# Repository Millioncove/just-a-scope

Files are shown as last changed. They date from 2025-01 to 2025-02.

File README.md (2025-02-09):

<p align="center">
  
</p>

# The simplest oscilloscope imaginable.
just-a-scope is a battery powered, ultra light, and tiny oscilloscope.

Often times when working on embedded projects, once GPIO has just been configured and you take the leap from programming into the real world, you cannot even get a blinky program running. Even if you are lucky enough to succeed in your LED-blinking, whatever you are moving onto next won't work. It is simply way more complicated than a single LED. 

At that point you wish you could "just see the electricity", but you cannot. You wish you had an oscilloscope, but all of the commercially available ones are extremely overkill and way out of budget. This is the problem just-a-scope tries to solve.

just-a-scope is really just an esp32 with some protection, scaling electronics and probes connected to the Analog-to-Digital converter. 9 times out of 10, that's all we'll ever need.

The plot is drawn in a web browser on a device connected over WIFI. At that point you already have the entire plot on your computer, and you can download a .csv file with all measurements made.

## Hardware
The microcontroller is an esp32s3, bought already soldered onto a SEEED Studio XIAO. This is a cheap and very small board which includes a USB-C connector as well as charging electronics for a lithium battery.

When buying one of these boards, you are likely to receive an antenna in the same package. This antenna is known to be unusable due to very poor signal, so a third party antenna must be used.

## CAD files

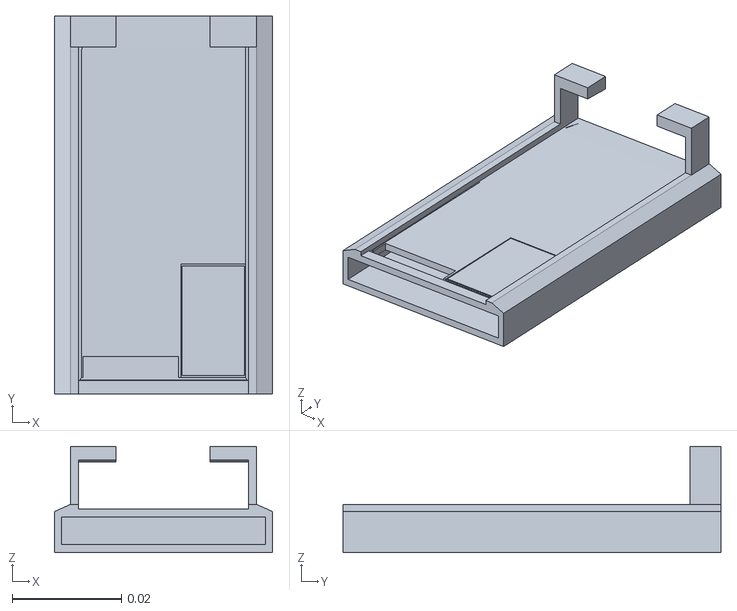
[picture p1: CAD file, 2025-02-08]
CAD/just-a-scope-lid.stl
0.0399 x 0.069 x 0.0194

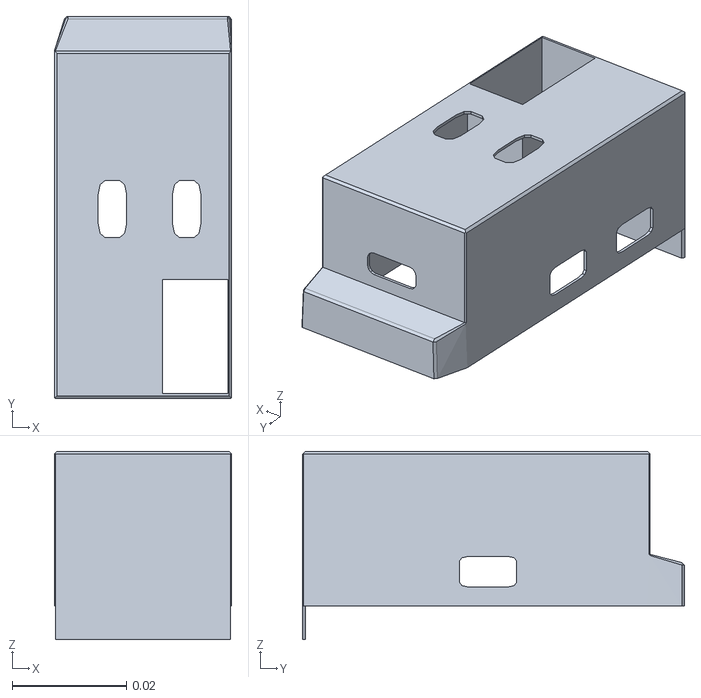
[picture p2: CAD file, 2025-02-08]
CAD/just-a-scope.stl
0.031 x 0.0668 x 0.0329

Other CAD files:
CAD/just-a-scope.blend

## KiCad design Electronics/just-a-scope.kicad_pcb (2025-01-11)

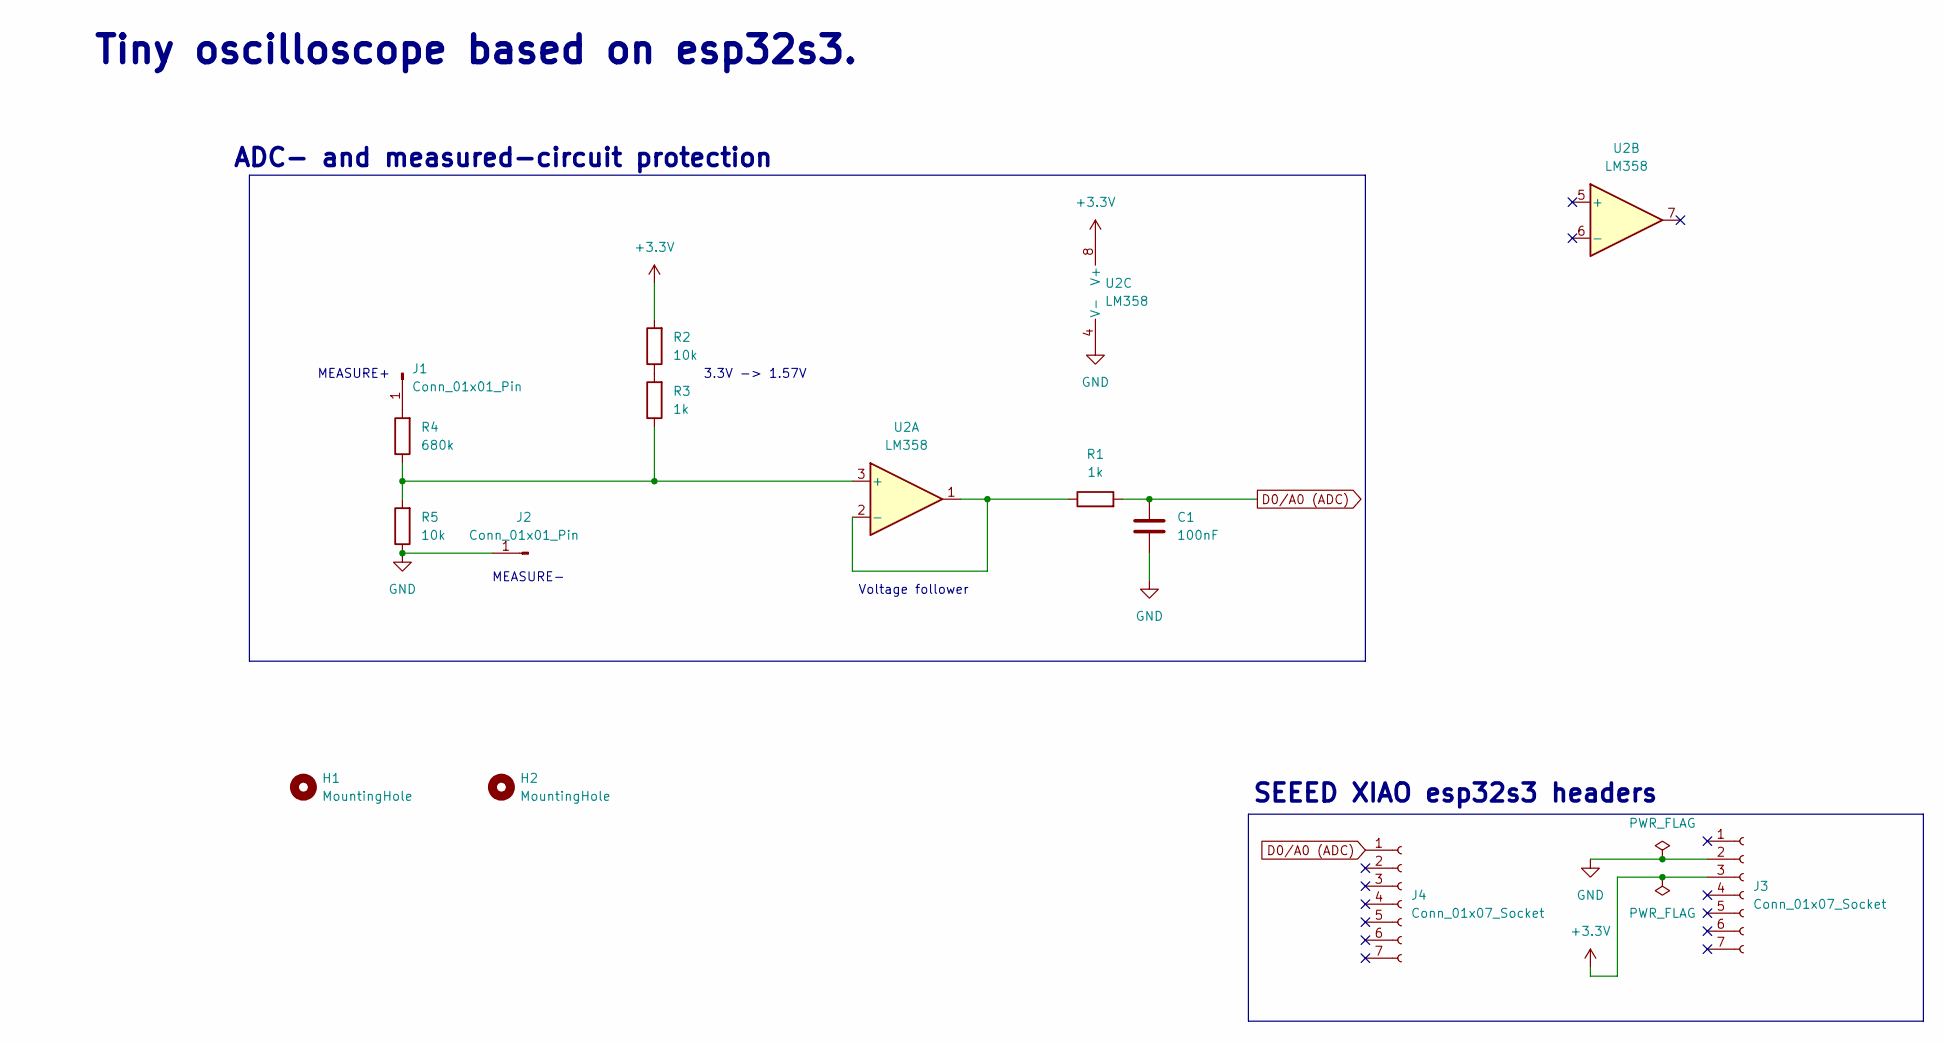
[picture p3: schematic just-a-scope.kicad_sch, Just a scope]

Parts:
C1: 100nF; C_0805_2012Metric
H1, H2: MountingHole; MountingHole_3.2mm_M3
J1, J2: Conn_01x01_Pin; SolderWirePad_1x01_SMD_5x10mm
J3, J4: Conn_01x07_Socket; PinSocket_1x07_P2.54mm_Vertical
R1, R3: 1k; R_0805_2012Metric
R2, R5: 10k; R_0805_2012Metric
R4: 680k; R_0805_2012Metric
U2: LM358; SOIC-8_3.9x4.9mm_P1.27mm

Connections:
+3.3V: J3.3, R2.2, U2.8 (V+)
D0/A0 (ADC): C1.1, J4.1, R1.2
GND: C1.2, J2.1, J3.2, R5.1, U2.4 (V-)
unnamed: J1.1, R4.2
unnamed: R2.1, R3.2
unnamed: R3.1, R4.1, R5.2, U2.3 (+)
unnamed: R1.1, U2.1, U2.2 (-)

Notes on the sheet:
3.3V -> 1.57V
Voltage follower
MEASURE+
MEASURE-
Tiny oscilloscope based on esp32s3.
ADC- and measured-circuit protection
SEEED XIAO esp32s3 headers

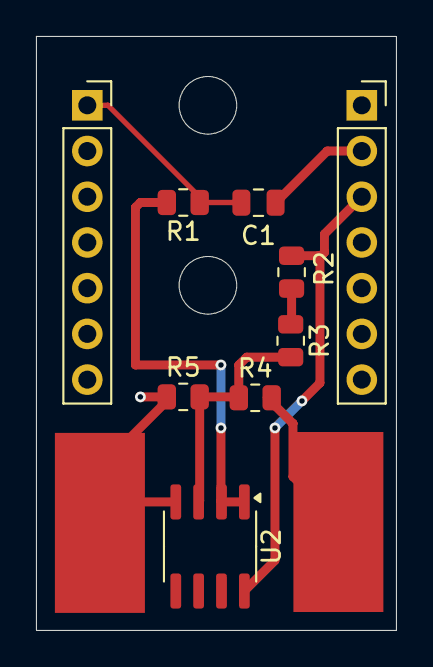
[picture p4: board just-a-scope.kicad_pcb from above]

Board: 2 copper layers, 20.0 x 33.0 mm, 13 parts (0 on the bottom side), 7 nets.

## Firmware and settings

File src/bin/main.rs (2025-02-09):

#![no_std]
#![no_main]

extern crate alloc;

use alloc::boxed::Box;
use core::{
    fmt::Debug,
    net::{Ipv4Addr, SocketAddr, SocketAddrV4},
    ptr::addr_of_mut,
};
use edge_http::{
    io::{
        server::{self as http, Handler},
        Error,
    },
    Method,
};
use edge_nal::{TcpAccept, TcpBind};
use edge_nal_embassy::{TcpBuffers, TcpError};
use embassy_net::{Config, Ipv4Cidr, Runner, Stack, StackResources, StaticConfigV4};
use embassy_time::{Duration, Timer};
use embedded_io_async::{Read, Write};
use embedded_websocket::{self as ws};
use esp_backtrace as _;
use esp_hal::{
    cpu_control::CpuControl,
    gpio::{Level, Output},
    peripherals::Peripherals,
    prelude::*,
    rng::Rng,
    timer::timg::TimerGroup,
};
use esp_println::println;
use esp_wifi::wifi::{AuthMethod, ClientConfiguration, WifiApDevice, WifiDevice, WifiStaDevice};
use esp_wifi::{
    self,
    wifi::{AccessPointConfiguration, Configuration},
};
use heapless::String;
use websocket_logistics::{send_message, CyclicBuffer, OscilliscopePoint};

mod measure;
mod websocket_logistics;

const POINTS_BUFFER_SIZE: usize = 128;
const SOCKETS_PER_STACK: usize = 16;
const TCP_SOCKETS_PER_WEBSOCKET: usize = 8;
const WEBSOCKET_SOCKET_BUFFERS_SIZE: usize = 500; // Probably too small...
const TCP_SOCKETS_PER_HTTP_SERVER: usize = 8;
const HTTP_SOCKET_BUFFERS_SIZE: usize = 500;
const CONNECTION_TIMEOUT_MS: u32 = 30_000;
const WEBSOCKET_PORT: u16 = 43822;
const HTTP_SERVER_PORT: u16 = 80;
const AP_GATEWAY_ADDRESS: Ipv4Addr = Ipv4Addr::new(192, 168, 1, 1);
const AP_WEBSOCKET_ENDPOINT: SocketAddrV4 = SocketAddrV4::new(AP_GATEWAY_ADDRESS, WEBSOCKET_PORT);
const STA_GATEWAY_ADDRESS: Ipv4Addr = Ipv4Addr::new(192, 168, 1, 1);
const STA_STATIC_IP_ADDRESS: Ipv4Addr = Ipv4Addr::new(192, 168, 1, 83);
const STA_WEBSOCKET_ENDPOINT: SocketAddrV4 =
    SocketAddrV4::new(STA_STATIC_IP_ADDRESS, WEBSOCKET_PORT);

static mut APP_CORE_STACK: esp_hal::cpu_control::Stack<640> =
    esp_hal::cpu_control::Stack::<640>::new();

static mut CONNECTED_TO_AP: bool = false;

// Get it?
#[embassy_executor::task]
async fn access_point_marathon(mut runner: Runner<'static, WifiDevice<'static, WifiApDevice>>) {
    runner.run().await
}

#[embassy_executor::task]
async fn station_marathon(mut runner: Runner<'static, WifiDevice<'static, WifiStaDevice>>) {
    runner.run().await
}

struct MyHttpHandler;

impl Handler for MyHttpHandler {
    type Error<T: Debug> = Error<T>;
    async fn handle<T, const N: usize>(
        &self,
        task_id: impl core::fmt::Display + Copy,
        conn: &mut http::Connection<'_, T, N>,
    ) -> Result<(), Self::Error<T::Error>>
    where
        T: Read + Write,
    {
        println!("Got a request! Task id: {task_id}");
        let request_headers = conn.headers()?;

        // Handle non-WebSocket requests.
        if Method::Get != request_headers.method {
            conn.initiate_response(405, Some("Method Not Allowed."), &[])
                .await?;
        } else if "/" != request_headers.path {
            conn.initiate_response(404, Some("Only the '/' path works right now."), &[])
                .await?;
            conn.write_all(b"Could not find the resource.").await?;
        } else {
            conn.initiate_response(200, Some("OK"), &[("Content-Type", "text/html")])
                .await?;
            conn.write_all(include_bytes!("web_page.html")).await?;
        }

        Ok(())
    }
}

#[embassy_executor::task(pool_size = 2)]
async fn http_server(stack: Stack<'static>, ip: Ipv4Addr) {
    let mut server = http::DefaultServer::new();

    let buffers: TcpBuffers<
        TCP_SOCKETS_PER_HTTP_SERVER,
        HTTP_SOCKET_BUFFERS_SIZE,
        HTTP_SOCKET_BUFFERS_SIZE,
    > = TcpBuffers::new();
    let tcp_instance: edge_nal_embassy::Tcp<
        '_,
        TCP_SOCKETS_PER_HTTP_SERVER,
        HTTP_SOCKET_BUFFERS_SIZE,
        HTTP_SOCKET_BUFFERS_SIZE,
    > = edge_nal_embassy::Tcp::new(stack, &buffers);
    let http_socket = tcp_instance
        .bind(core::net::SocketAddr::V4(SocketAddrV4::new(
            ip,
            HTTP_SERVER_PORT,
        )))
        .await
        .expect("Failed to bind http socket.");

    server
        .run(Some(CONNECTION_TIMEOUT_MS), http_socket, MyHttpHandler)
        .await
        .expect("Actually running the http server failed.");
}

#[embassy_executor::task(pool_size = 2)]
async fn web_socket_server(
    stack: Stack<'static>,
    point_buffer: &'static CyclicBuffer<POINTS_BUFFER_SIZE, OscilliscopePoint>,
    address_and_port: SocketAddr,
) {
    'single_web_socket: loop {
        // Set up the underlying TCP socket and listen for a WebSocket handshake request.
        let buffers: TcpBuffers<
            TCP_SOCKETS_PER_WEBSOCKET,
            WEBSOCKET_SOCKET_BUFFERS_SIZE,
            WEBSOCKET_SOCKET_BUFFERS_SIZE,
        > = TcpBuffers::new();
        let tcp_instance: edge_nal_embassy::Tcp<
            '_,
            TCP_SOCKETS_PER_WEBSOCKET,
            WEBSOCKET_SOCKET_BUFFERS_SIZE,
            WEBSOCKET_SOCKET_BUFFERS_SIZE,
        > = edge_nal_embassy::Tcp::new(stack, &buffers);
        let web_socket = tcp_instance
            .bind(address_and_port)
            .await
            .expect("Failed to bind WebSocket.");
        let (endpoint, mut web_socket) = web_socket
            .accept()
            .await
            .expect("Something went wrong when expecting a connection to the websocket.");

        // Something connected. Make sure it sent a http message. (WebSocket handshakes are http messages)
        let mut header_buffer = [0u8; WEBSOCKET_SOCKET_BUFFERS_SIZE];
        let mut bytes_read: usize = 0;
        loop {
            match web_socket.read(&mut header_buffer).await {
                Ok(0) => break,
                Ok(s) => bytes_read += s,
                Err(e) => {
                    println!(
                        "Received a garbled WebSocket handshake request. Error: {:?}",
                        e
                    );
                    continue 'single_web_socket;
                }
            }
            if &header_buffer[bytes_read - 4..bytes_read] == b"\r\n\r\n" {
                // Data is definitely a http message at least.
                break;
            } else {
                println!("Received data, but it was not http (so also not a WebSocket handshake).");
            }
        }

        // Definitely received a http message at this point. Extract WebSocket handshake data from the headers.
        let mut headers = [httparse::EMPTY_HEADER; 16];
        let mut request = httparse::Request::new(&mut headers);
        request.parse(&header_buffer).unwrap();
        let headers = request.headers.iter().map(|f| (f.name, f.value));
        let ws_context = ws::read_http_header(headers).unwrap().unwrap();

        // At this point we have a definite handshake request. Send a handshake approval response.
        let mut ws_server = ws::WebSocketServer::new_server();
        let mut handshake_approval = [0u8; WEBSOCKET_SOCKET_BUFFERS_SIZE];
        let len = ws_server
            .server_accept(
                &ws_context.sec_websocket_key,
                ws_context.sec_websocket_protocol_list.first(),
                &mut handshake_approval,
            )
            .expect("Creating WebSocket handshake response failed.");
        web_socket
            .write_all(&handshake_approval[..len])
            .await
            .expect("Could not write the WebSocket handshake response to the socket.");

        println!(
            "WebSocket connection should be successfully opened on {}. Taking ownership of buffer reader...",
            endpoint
        );

        let reader = match point_buffer.take_reader() {
            Some(r) => r,
            None => {
                println!("Reader was already taken.");
                continue 'single_web_socket;
            }
        };

        loop {
            // Send data to the WebSocket.
            let batches = &reader.get_batch_holder().batches;

            for batch in batches {
                for batch in batch.chunks(112) {
                    assert!(
                        batch.len() % 8 == 0,
                        "Trying to send data with length not a multiple of 8"
                    );

                    match send_message(&mut web_socket, batch).await {
                        Ok(_) => (),
                        Err(TcpError::General(embassy_net::tcp::Error::ConnectionReset)) => {
                            println!("WebSocket connection was closed.");
                            continue 'single_web_socket;
                        }
                        Err(e) => panic!("Sending WebSocket message failed: {e:?}"),
                    }
                }
            }

            // Flush the WebSocket. Leads to weird behavior if not done.
            web_socket
                .flush()
                .await
                .expect("Failed to flush WebSocket.");
        }
    }
}

fn auth_method_from_str(auth_str: &str) -> AuthMethod {
    match auth_str {
        "none" => return AuthMethod::None,
        "wep" => {
            return AuthMethod::WEP;
        }
        "wpa" => {
            return AuthMethod::WPA;
        }
        "wapipersonal" => {
            return AuthMethod::WAPIPersonal;
        }
        "wpa2enterprise" => {
            return AuthMethod::WPA2Enterprise;
        }
        "wpa2personal" => {
            return AuthMethod::WPA2Personal;
        }
        "wpa2wpa3personal" => {
            return AuthMethod::WPA2WPA3Personal;
        }
        "wpa3personal" => {
            return AuthMethod::WPA3Personal;
        }
        "wpawpa2personal" => {
            return AuthMethod::WPAWPA2Personal;
        }
        _ => panic!("Configuration value for station auth method '{auth_str}' is invalid."),
    }
}

#[main]
async fn main(spawner: embassy_executor::Spawner) -> ! {
    // Initialize heap, logger, and peripherals.
    esp_alloc::heap_allocator!(72 * 1024);
    esp_println::logger::init_logger_from_env();
    let peripherals: Peripherals = esp_hal::init({
        let mut config: esp_hal::Config = esp_hal::Config::default();
        config.cpu_clock = CpuClock::max();
        config
    });

    // Construct the buffer that will store the voltage measurements.
    let point_buffer: &'static CyclicBuffer<POINTS_BUFFER_SIZE, OscilliscopePoint> =
        Box::leak(Box::new(CyclicBuffer::new(OscilliscopePoint {
            voltage: 10f64,
            second: 10f64,
        })));

    let mut writer = point_buffer.take_writer().unwrap();

    // Initialize embassy so async works at all.
    let timg1 = TimerGroup::new(peripherals.TIMG1);
    esp_hal_embassy::init(timg1.timer0);

    // Set up wifi peripheral.
    let timg0 = TimerGroup::new(peripherals.TIMG0);
    let esp_wifi_controller: Box<esp_wifi::EspWifiController<'static>> = Box::new(
        esp_wifi::init(
            timg0.timer0,
            Rng::new(peripherals.RNG),
            peripherals.RADIO_CLK,
        )
        .unwrap(),
    );
    let esp_wifi_controller = Box::leak(esp_wifi_controller);

    let (ap_device, sta_device, mut controller) =
        esp_wifi::wifi::new_ap_sta(esp_wifi_controller, peripherals.WIFI).unwrap();

    // Station stack setup.
    let sta_stack_conf = Config::ipv4_static(StaticConfigV4 {
        address: Ipv4Cidr::new(STA_STATIC_IP_ADDRESS, 24),
        gateway: Some(STA_GATEWAY_ADDRESS),
        dns_servers: Default::default(),
    });
    let sta_resources = Box::leak(Box::new(StackResources::<SOCKETS_PER_STACK>::new()));
    let random_seed = 35181354; // Extremely secure!
    let (sta_stack, sta_runner) =
        embassy_net::new(sta_device, sta_stack_conf, sta_resources, random_seed);

    // Access point network stack setup.
    let ap_stack_conf = Config::ipv4_static(StaticConfigV4 {
        address: Ipv4Cidr::new(AP_GATEWAY_ADDRESS, 24),
        gateway: Some(AP_GATEWAY_ADDRESS),
        dns_servers: Default::default(),
    });
    let ap_resources = Box::leak(Box::new(StackResources::<SOCKETS_PER_STACK>::new()));
    let random_seed = 687486766; // Extremely secure!
    let (ap_stack, ap_runner) =
        embassy_net::new(ap_device, ap_stack_conf, ap_resources, random_seed);

    // Station configuration.
    let sta_conf: ClientConfiguration = ClientConfiguration {
        ssid: String::<32>::try_from(env!("station_ssid")).expect("Station ssid has wrong format."),
        auth_method: auth_method_from_str(env!("station_auth_method")),
        password: String::<64>::try_from(env!("station_password"))
            .expect("Station password has wrong format."),
        ..ClientConfiguration::default()
    };

    // Access point configuration.
    let ap_conf: AccessPointConfiguration = AccessPointConfiguration {
        ssid: String::<32>::try_from(env!("access_point_ssid")).expect("AP ssid has wrong format."),
        auth_method: auth_method_from_str(env!("access_point_auth_method")),
        password: String::<64>::try_from(env!("access_point_password"))
            .expect("AP password has wrong format."),
        ..AccessPointConfiguration::default()
    };
    println!(
        "Configured to connect to {}. Starting the wifi access point...",
        sta_conf.ssid
    );

    // Apply wifi configurations.
    controller
        .set_configuration(&Configuration::Mixed(sta_conf, ap_conf))
        .expect("Failed to set the wifi configurations...");

    // Start the wifi access point and station.
    controller
        .start()
        .expect("Welp, could not start the wifi controller...");

    // Start running the stacks concurrently.
    spawner
        .spawn(access_point_marathon(ap_runner))
        .expect("Could not start access point stack runner task.");
    spawner
        .spawn(station_marathon(sta_runner))
        .expect("Could not start station stack runner task.");

    // Block until the stack is ready.
    loop {
        if ap_stack.is_link_up() {
            break;
        }
        embassy_time::Timer::after(embassy_time::Duration::from_millis(500)).await;
    }

    // Start the servers!
    println!("Starting http servers!");
    spawner
        .spawn(http_server(ap_stack, AP_GATEWAY_ADDRESS))
        .expect("Failed to spawn access point http server task.");
    spawner
        .spawn(http_server(sta_stack, STA_STATIC_IP_ADDRESS))
        .expect("Failed to spawn station http server task.");
    println!("Starting WebSocket servers!");
    spawner
        .spawn(web_socket_server(
            ap_stack,
            &point_buffer,
            SocketAddr::V4(AP_WEBSOCKET_ENDPOINT),
        ))
        .expect("Failed to spawn access point WebSocket server task.");
    spawner
        .spawn(web_socket_server(
            sta_stack,
            &point_buffer,
            SocketAddr::V4(STA_WEBSOCKET_ENDPOINT),
        ))
        .expect("Failed to spawn station WebSocket server task.");

    // Spawn the process on the second core that actually performs the measurements.
    let mut cpu_control = CpuControl::new(peripherals.CPU_CTRL);

    // Get standard values from config.toml
    let reference_voltage: f64 = env!("adc_reference_voltage").parse().unwrap();
    let probes_shorted_voltage: f64 = env!("probes_shorted").parse().unwrap();
    let max_voltage: f64 = env!("max_voltage_absolute").parse().unwrap();
    let tolerance_factor: f64 = env!("tolerance_factor").parse().unwrap();
    let min_voltage_difference: f64 = env!("min_voltage_difference").parse().unwrap();
    let samples_per_point: u32 = env!("samples_per_point").parse().unwrap();

    let snd_core_fn = || {
        measure::measuring_task(
            peripherals.ADC1,
            peripherals.GPIO1,
            &mut writer,
            reference_voltage,
            probes_shorted_voltage,
            max_voltage,
            tolerance_factor,
            min_voltage_difference,
            samples_per_point,
        )
    };

    let _guard = cpu_control
        .start_app_core(unsafe { &mut *addr_of_mut!(APP_CORE_STACK) }, snd_core_fn)
        .unwrap();

    // Blinky.
    let mut led: Output = Output::new(peripherals.GPIO21, Level::Low);
    println!("The setup didn't crash! Starting blink loop...");
    let mut mac = [0u8; 6];
    esp_wifi::wifi::sta_mac(&mut mac);
    println!("My wifi MAC is {:x?}", mac);
    try_connect(&mut controller);
    loop {
        unsafe {
            println!("Missed: {}", *point_buffer.missed.get());
        }
        Timer::after(Duration::from_millis(7000)).await;
        led.toggle();
    }
}

fn try_connect(controller: &mut esp_wifi::wifi::WifiController) {
    unsafe {
        if CONNECTED_TO_AP {
            return;
        }
    }

    match controller.is_connected() {
        Ok(true) => (),
        Ok(false) | Err(esp_wifi::wifi::WifiError::Disconnected) => {
            println!("Trying to connect to access point as station...");
            match controller.connect() {
                Ok(_) => match controller.is_connected() {
                    Ok(true) => {
                        println!("Connection to access point network established!");
                        unsafe {
                            CONNECTED_TO_AP = true;
                        }
                    }
                    Ok(false) => {
                        println!("Connection to access point may have succeeded or failed (???)")
                    }
                    Err(e) => println!("Failed to connect to access point: {e:?}"),
                },
                Err(e) => println!("Failed when trying to connect: '{e:?}'"),
            }
        }
        _ => println!("Failed to check if connected to access point."),
    }
}

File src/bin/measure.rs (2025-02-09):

use crate::websocket_logistics::{
    is_middle_point_removable_complicated, CyclicWriter, OscilliscopePoint,
};
use esp_hal::{
    analog::adc::{Adc, AdcCalBasic, AdcChannel, AdcConfig, Attenuation},
    gpio::{AnalogPin, GpioPin},
    peripherals::ADC1,
    prelude::nb,
    time::now,
};

fn take_measurement<const PIN: u8>(
    adc: &mut Adc<'_, ADC1>,
    pin: &mut esp_hal::analog::adc::AdcPin<GpioPin<PIN>, ADC1, AdcCalBasic<ADC1>>,
    samples_per_point: u32,
) -> u16
where
    GpioPin<PIN>: AdcChannel + AnalogPin,
{
    let mut sum = 0u32;
    for _ in 0..samples_per_point {
        sum += nb::block!(adc.read_oneshot(pin)).unwrap() as u32;
    }

    return (sum / samples_per_point).try_into().unwrap();
}

pub fn measuring_task<const L: usize, const PIN: u8>(
    adc_peripheral: ADC1,
    pin: GpioPin<PIN>,
    point_buffer_writer: &mut CyclicWriter<'_, L, OscilliscopePoint>,
    reference_voltage: f64,
    probes_shorted_voltage: f64,
    max_voltage: f64,
    tolerance_factor: f64,
    min_voltage_difference: f64,
    samples_per_point: u32,
) -> !
where
    GpioPin<PIN>: AdcChannel + AnalogPin,
{
    let mut adc_config = AdcConfig::new();

    let mut pin =
        adc_config.enable_pin_with_cal::<_, AdcCalBasic<_>>(pin, Attenuation::Attenuation11dB);
    let mut adc = Adc::new(adc_peripheral, adc_config);

    let mut before_last: OscilliscopePoint = OscilliscopePoint {
        voltage: 0f64,
        second: 0f64,
    };
    let mut last: OscilliscopePoint = OscilliscopePoint {
        voltage: 0.01f64,
        second: 0.01f64,
    };

    loop {
        let current_second: f64 = now().ticks() as f64 / 1_000_000f64;
        let raw_adc_output = take_measurement(&mut adc, &mut pin, samples_per_point);
        let raw_adc_voltage = raw_adc_output as f64 * reference_voltage / 4095f64;
        let adjusted_voltage = (raw_adc_voltage - probes_shorted_voltage) * max_voltage * 2f64
            / reference_voltage
            - probes_shorted_voltage;
        let new_point = OscilliscopePoint {
            voltage: adjusted_voltage,
            second: current_second,
        };

        let time_difference = last.second - before_last.second;

        if time_difference > 1f64
            || !is_middle_point_removable_complicated(
                &before_last,
                &last,
                &new_point,
                tolerance_factor,
                min_voltage_difference,
            )
        {
            match point_buffer_writer.append(last.clone()) {
                Ok(_) => (),
                Err(_) => (),
            }

            before_last = last;
        }
        last = new_point;
    }
}

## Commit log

2024-12-16 TCP socket works! (barely)
2024-12-23 Better framework for sending WebSocket messages.
2025-01-01 Now filters out redundant points! Cleaning needed...
2025-01-09 Now measures voltage.
2025-01-11 Electronics and pcb.
    [just-a-scope.kicad_pcb, just-a-scope.kicad_sch]
2025-01-11 Added calibration to ADC.
2025-01-13 Adjustments for voltage from measurement circuit.
2025-01-14 Multisampling to reduce noise.
    [measure.rs]
2025-01-14 More reasonable voltage range. (code only)
2025-01-15 Fullscreen, fading buttons, UX.
2025-01-19 Battery-less enclosure CAD.
    [just-a-scope-lid.stl, just-a-scope.blend, just-a-scope.stl]
2025-02-08 Enclosure with battery.
    [just-a-scope-lid.stl, just-a-scope.blend, just-a-scope.stl]
2025-02-09 Bugfix: Only half of voltage measured.
    [measure.rs]
